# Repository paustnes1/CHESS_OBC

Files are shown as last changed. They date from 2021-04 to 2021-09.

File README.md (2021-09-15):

# CHESS OBC Revision 1.0

This PCB is the On-Board-Computer for the CHESS mission of the EPFL Spacecraft Team. It's core components are an FPGA which can be re-programmed via a PIC-Microcontroller. Furthermore the board hosts SRAM, FRAM, Flash, PC104 connector and some more smaller components.

The main project is in the Folder "CHESSOBC_rev1". The bill of materials (BOM) and the component placement list (CPL) is provided in Excel format. The zip contains the Gerber files which are used to produce the board.

The PCB is still in development and not in a final state.

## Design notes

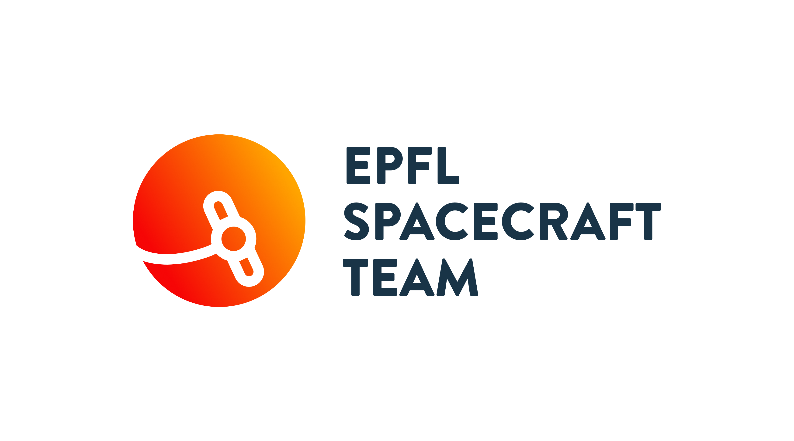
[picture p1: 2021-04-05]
CHESSOBC_rev1/SpacecraftTeam_light_BG.png

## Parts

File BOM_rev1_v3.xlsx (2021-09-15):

Designator | Manufacturer Nr. | Quantity | Type | Name | Description | Price / Unit | Mouser Link | Availability | LibRef
C1, C2, C4, C5, C7, C9, C10, C12, C13, C14, C15, C17, C19, C21, C23, C25, C27, C31, C33, C35, C37, C39, C41, C45, C47, C50, C52, C54, C56, C59, C63, C65, C69, C71, C74, C76, C80, C82, C87, C89 | GCM155L8EH104KE07D | 40 | Capacitor | 1005 | 100 nF | Fr.0.14 | GCM155L8EH104KE07D Murata Electronics | Mouser Schweiz (https://www.mouser.ch/ProductDetail/Murata-Electronics/GCM155L8EH104KE07D) | 302'380 in stock | CMP-2008-02046-1
C3 | JMK105BJ334KV-F | 1 | Capacitor | 1005 | 0.33 uF | Fr.0.11 | JMK105BJ334KV-F Taiyo Yuden | Mouser Schweiz (https://www.mouser.ch/ProductDetail/Taiyo-Yuden/JMK105BJ334KV-F) | 16'324 in stock | CMP-03422-001340-1
C6, C16, C18, C20, C22, C24, C26, C28, C29, C30, C32, C34, C36, C38, C40, C42, C43, C44, C46, C49, C51, C55, C57, C62, C64, C66, C68, C70, C73, C75, C78, C79, C81, C83, C86, C88 | 04025C103K4T2A | 36 | Capacitor | 1005 | 10 nF | Fr.0.09 | 04025C103K4T2A AVX | Mouser Schweiz (https://www.mouser.ch/ProductDetail/AVX/04025C103K4T2A) | 9382 in stock | CMP-1034-01878-1
C48, C53, C67, C77 | TMR107B7105KA-T | 4 | Capacitor | 1608 | 1 uF | Fr.0.24 | https://www.mouser.ch/ProductDetail/Taiyo-Yuden/TMR107B7105KA-T | 15'785 in stock | CMP-2000-06025-1
C58 | JMK212BBJ226MG8T | 1 | Capacitor | 0805 inches | 22 uF | Fr.0.27 | https://www.mouser.ch/ProductDetail/Taiyo-Yuden/JMK212BBJ226MG8T | 4960 in stock | CMP-001-00081-2
C100 | HMR325AC7475KM-P | 1 | Capacitor | 3225 | 4.7 uF | Fr.1.12 | https://www.mouser.ch/ProductDetail/Taiyo-Yuden/HMR325AC7475KM-P?qs=DPoM0jnrROVWw6RJv0JMZg%3D%3D | 1797 in stock | CMP-1038-02151-2
C8, C101 | LMK212AC6106KD-T | 2 | Capacitor | 0805 inches | 10 uF |  |  |  | CMP-2007-03243-2
COM-Header | 67996-420HLF | 1 | Header | 10X2 | COM-Header | Fr.0.69 | 67996-420HLF Amphenol FCI | Mouser Schweiz (https://www.mouser.ch/ProductDetail/Amphenol-FCI/67996-420HLF?qs=QKvFUfBIyQIvQWWcVN8Heg%3D%3D) | 6272 in stock
D1, D2 | ESD7351XV2T5G | 2 | Diode | T3V3S5 |  | Fr.0.41 | ESD7351XV2T5G ON Semiconductor | Mouser Schweiz (https://www.mouser.ch/ProductDetail/ON-Semiconductor/ESD7351XV2T5G?qs=byeeYqUIh0NOrh0ZBfew0g%3D%3D) | 7980 in stock | CMP-1063-00100-1
FLASH | IS37SML01G1-LLI | 1 | Flash | TC58CVG0S3HRAIJ | 1 Gbit | Fr.4.44 | IS37SML01G1-LLI ISSI | Mouser Schweiz (https://www.mouser.ch/ProductDetail/ISSI/IS37SML01G1-LLI?qs=YCa%2FAAYMW01%2FaQ6kjHyDew%3D%3D) | 928 in stock
FRAM | FM22LD16-55-BG | 1 | FRAM | FM22LD16-55-BG |  | Fr.39.50 | FM22LD16-55-BG Cypress Semiconductor | Mouser Schweiz (https://www.mouser.ch/ProductDetail/Cypress-Semiconductor/FM22LD16-55-BG?qs=pA5MXup5wxF9f7BYMzo1gA%3D%3D) | 1332 in stock
J1, J2 | ESQ-126-39-G-D | 2 | PC-104 | ESQ-126-23-T-D
PIC-Kit | 10129378-905003BLF | 1 | Header | 1X5 |  | Fr.0.17 | https://www.mouser.ch/ProductDetail/Amphenol-FCI/10129378-905003BLF?qs=0lQeLiL1qyYbn8n2WZpgeA%3D%3D | 3541 in stock
L2 | L0805C6R8MPWST | 1 | Inductor | 2012 | 6.8 uH | Fr.0.25 | https://www.mouser.ch/ProductDetail/KEMET/L0805C6R8MPWST?qs=gt1LBUVyoHlTFiSy3m2gEA%3D%3D | 2533 in stock
L3 | LQM21PN2R2NGCD | 1 | Inductor | 2012 | 2.2 uH | Fr.0.27 | LQM21PN2R2NGCD Murata Electronics | Mouser Schweiz (https://www.mouser.ch/ProductDetail/Murata-Electronics/LQM21PN2R2NGCD) | 95 in stock
5V-LED | BR1101W-TR | 2 | LED | RPG1102W-660-TR |  | Fr.0.38 | BR1101W-TR Stanley Electric | Mouser Schweiz (https://www.mouser.ch/ProductDetail/Stanley-Electric/BR1101W-TR?qs=byeeYqUIh0Pp62ktTXSSvA%3D%3D) | 16'982 in stock
LED_FPGA_1, LED_FPGA_2, LED_FPGA_3 | SMLD12BN1WT86 | 3 | LED | SMLD12BN1WT86 |  | Fr.0.66 | SMLD12BN1WT86 ROHM Semiconductor | Mouser Schweiz (https://www.mouser.ch/ProductDetail/ROHM-Semiconductor/SMLD12BN1WT86) | 6915 in stock
GPIO | 10129381-940002BLF | 1 | Header | Header 20X2 | GPIO-Header | Fr.0.77 | 10129381-940002BLF Amphenol FCI | Mouser Schweiz (https://www.mouser.ch/ProductDetail/Amphenol-FCI/10129381-940002BLF?qs=0lQeLiL1qybDkBpXY7DYcQ%3D%3D) | 357 in stock
PIC | PIC18LF26K83-I/SO | 1 | PIC | PIC18LF26K83-I/SO |  | Fr.2.00 | PIC18LF26K83-I/SO Microchip Technology | Mouser Schweiz (https://www.mouser.ch/ProductDetail/Microchip-Technology/PIC18LF26K83-I-SO/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) | 354 in stock
R1, R7, R9, R10, R11 | SG73P1EWTTP1002F | 5 | Resistor | RESC1005X40X25LL05T10 | 10 kOhm | Fr.0.27 | SG73P1EWTTP1002F KOA Speer | Mouser Schweiz (https://www.mouser.ch/ProductDetail/KOA-Speer/SG73P1EWTTP1002F) | 9600 in stock | CMP-2002-07353-1
R2 | ERA-2VEB2200X | 1 | Resistor | RESC1005X40X25ML05T10 | 220 Ohm | Fr.0.48 | ERA-2VEB2200X Panasonic | Mouser Schweiz (https://www.mouser.ch/ProductDetail/Panasonic/ERA-2VEB2200X?qs=sGAEpiMZZMtlubZbdhIBIFX24rZb7BVExcGQh2y83fs%3D) | 7790 in stock | CMP-2002-07511-1
R6 | MCS04020D1200BE000 | 1 | Resistor | RESC1005X40X25LL05T10 | 0 Ohm | Fr.0.43 | MCS04020D1200BE000 Vishay / Beyschlag | Mouser Schweiz (https://www.mouser.ch/ProductDetail/Vishay-Beyschlag/MCS04020D1200BE000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) | 19'725 in stock | CMP-2002-07353-1
R8 | MCS04020D4701BE000 | 1 | Resistor | RESC1005X40X25LL05T10 | 4.7 kOhm | Fr.0.51 | MCS04020D4701BE000 Vishay / Beyschlag | Mouser Schweiz (https://www.mouser.ch/ProductDetail/Vishay-Beyschlag/MCS04020D4701BE000) | 9990 in stock | CMP-2002-07353-1
R14, R15, R16, R17 | PA0603-R-070RL | 4 | Resistor | CRCW06030000Z0EA | 0 Ohm | Fr.0.53 | PA0603-R-070RL YAGEO | Mouser Schweiz (https://www.mouser.ch/ProductDetail/YAGEO/PA0603-R-070RL?qs=sGAEpiMZZMtlubZbdhIBIKX7RhrzB5EAvnsYZcgjSGA%3D) | 27'430 in stock
R18, R19, R20, R21, R22, R23 | CHP1206AFX-4701ELF | 6 | Resistor | CHP1206AFX-4701ELF | 4.7 kOhm | Fr.0.66 | CHP1206AFX-4701ELF Bourns | Mouser Schweiz (https://www.mouser.ch/ProductDetail/Bourns/CHP1206AFX-4701ELF) | 3331 in stock
R24, R25 | PTN0805Y1002BST1 | 2 | Resistor | PTN0805Y1002BST1 | 10 kOhm | Fr.1.40 | PTN0805Y1002BST1 Vishay / Thin Film | Mouser Schweiz (https://www.mouser.ch/ProductDetail/Vishay-Thin-Film/PTN0805Y1002BST1) | 1656 in stock
R100 | RC1206JR-07180RL | 1 | Resistor | RC1206JR-07180RL | 180 Ohm | Fr.0.19 | RC1206JR-07180RL YAGEO | Mouser Schweiz (https://www.mouser.ch/ProductDetail/YAGEO/RC1206JR-07180RL?qs=CteSnpDdeuBlMmDLUHPycw%3D%3D) | 172'831 in stock
R101 | RN73H2ATTD75R0B25 | 1 | Resistor | RN73H2ATTD75R0B25 | 75 Ohm | Fr.0.73 | RN73H2ATTD75R0B25 KOA Speer | Mouser Schweiz (https://www.mouser.ch/ProductDetail/KOA-Speer/RN73H2ATTD75R0B25) | 4'997 in stock
R_LED3_80Ohm, R_LED4_80Ohm, R_LED5_80Ohm | RCS060382R0FKEA | 3 | Resistor | RCS060382R0FKEA | 82 Ohm | Fr.0.15 | RCS060382R0FKEA Vishay / Dale | Mouser Schweiz (https://www.mouser.ch/ProductDetail/Vishay-Dale/RCS060382R0FKEA) | 5'286 in stock
SRAM | CY62167GE30-45BV1XI | 1 | SRAM | CY62167GE30-45BV1XI | 16 Mbit | Fr.18.13 | CY62167GE30-45BV1XI Cypress Semiconductor | Mouser Schweiz (https://www.mouser.ch/ProductDetail/Cypress-Semiconductor/CY62167GE30-45BV1XI?qs=3FnuM6ZipRIEqfAGSsiEJg%3D%3D) | 194 in stock
TempSensor | TMP144YFFT | 1 | Temperatur Sensor | TMP144YFFT |  | Fr.0.77 | TMP144YFFT Texas Instruments | Mouser Schweiz (https://www.mouser.ch/ProductDetail/Texas-Instruments/TMP144YFFT?qs=w%2Fv1CP2dgqo7c%252BU2xzWt2g%3D%3D) | 2130 in stock
U1 | A3P1000-1FGG484 | 1 | FPGA | A3P1000-1FGG484
CurrentSensing | INA138QPWRQ1 | 1 | Current Sense Amplifier | INA138QPWRQ1
1.5V-Supply | LM3671MF-3.3/NOPB | 1 | DC-DC Step down | LM3671MF-3.3/NOPB |  | Fr.1.52 | LM3671MF-3.3/NOPB Texas Instruments | Mouser Schweiz (https://www.mouser.ch/ProductDetail/Texas-Instruments/LM3671MF-33-NOPB?qs=QbsRYf82W3E7NHceZ4TukA%3D%3D) | 216 in stock
X1-(JTAG) | 77311-462K05LF | 1 | Header | 77311-462K05LF | PIC Header | Fr.0.82 | 77311-462K05LF Amphenol FCI | Mouser Schweiz (https://www.mouser.ch/ProductDetail/Amphenol-FCI/77311-462K05LF) | 337 in stock
FPGA-CLK | ECS-2033-320-AU | 1 | Oscilloscope | ECS-2033-320-AU |  | Fr.1.87 | ECS-2033-320-AU ECS | Mouser Schweiz (https://www.mouser.ch/ProductDetail/ECS/ECS-2033-320-AU) | 1595 in stock

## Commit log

2021-03-26 push first version
    [CHESSOBC_rev1.GBL, CHESSOBC_rev1.GBO, CHESSOBC_rev1.GBP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]
2021-03-27 Moved capacitors to FPGA
    First I deleted all the Components that were on our board. Then I copy pasted the layout from the Sapristi board. By "Design->Import changes..." all the connections should again be correct. The footprint was thereby changed to the same footprints we had before. Finally I changed to orientation of the capacitors to match with the ones of Sapristi.
    [CHESSOBC_rev1.GBL, CHESSOBC_rev1.GBO, CHESSOBC_rev1.GBP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]
2021-03-27 partially added debug interface
    [CHESSOBC_rev1.PrjPcb, GPIO_Headers.SchDoc]
2021-03-28 started on title block
    currently the new title block is on no schematic
    [CHESSOBC_rev1.PrjPcb, CHESSOBC_rev1.SCHLIB]
2021-03-29 added led circuits with correct components
    [CHESSOBC_rev1.PrjPcb, Core.SchDoc, GPIO_Headers.SchDoc]
2021-03-29 add3ed fram footprint
    [Core.SchDoc]
2021-03-29 added sram footprint
    [Core.SchDoc]
2021-03-29 Added 1V5 regulator for FPGA core
    [CHESSOBC_rev1.PcbDoc, Power.SchDoc]
2021-03-29 New FRAM and SRAM routed. Moved LEDs
    FRAM and SRAM has correct footprint
    LEDs and test points are moved to the power schematic to keep the structure. GPIO-headers should probably be moved to interface schematic. Footprints for leds must be updated
    [CHESSOBC_rev1.PcbDoc, Core.SchDoc, FPGABanks.SchDoc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]
2021-03-31 new leds with lower power consumption
    [CHESSOBC_rev1.PcbDoc, Interface.SchDoc, Power.SchDoc]
2021-04-02 Finished Title Block
    [CHESSOBC_rev1.PrjPcb, CHESSOBC_rev1.SCHLIB, Core.SchDoc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]
2021-04-03 Set up layer stack manager
    6 layers. Changed to mm. Added routing design rules
    [CHESSOBC_rev1.PcbDoc, CHESSOBC_rev1.PrjPcb, Core.SchDoc]
2021-04-03 started routing fram
    [CHESSOBC_rev1.PcbDoc, CHESSOBC_rev1.PrjPcb, FPGABanks.SchDoc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]
2021-04-05 TitleBlock, PC104 connections, FPGA/Ram placement
    TitleBlock: added Designer initials and fixed pictures
    PC104: Compared to endurosat and removed connections that don't exist on endurosat
    Placement: Placed FPGA, Sram and Fram in a place where it seems good
    [CHESSOBC_rev1.PcbDoc, CHESSOBC_rev1.PrjPcb, CHESSOBC_rev1.SCHLIB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]
2021-04-05 no big changes
    [CHESSOBC_rev1.PrjPcb, Core.SchDoc, FPGABanks.SchDoc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]
2021-04-05 Reconnected PC104 pins
    [Interface.SchDoc]
2021-04-05 pdf output job
    [CHESSOBC_rev1.PcbDoc]
2021-04-06 small changes
    [Memory.SchDoc]
2021-04-06 PC104 and cleanup of all comm pins
    [FPGABanks.SchDoc, GPIO_Headers.SchDoc, Interface.SchDoc]
2021-04-06 all connections (except 1.5V power) should be fine now
    [CHESSOBC_rev1.PcbDoc, FPGABanks.SchDoc, Housekeeping.SchDoc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]
2021-04-06 small error fix
    [CHESSOBC_rev1.PcbDoc]
2021-04-07 some changes for AP3000 comp.
    [FPGABanks.SchDoc, Interface.SchDoc]
2021-04-07 added current sensing
    [CHESSOBC_rev1.PcbDoc, Power.SchDoc]
2021-04-07 final cleaning before schem review
    [CHESSOBC_rev1.PcbDoc, FPGABanks.SchDoc, FPGABanks.~(6).SchDoc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]
2021-04-15 fpga fanout
    [CHESSOBC_rev1.PcbDoc]
2021-04-24 SRAM and FRAM fanout
    Fanout of SRAM and FRAM
    +Placement of a capacitor below FRAM
    [CHESSOBC_rev1.PcbDoc]
2021-04-27 Via placement for FPGA
    New design rule for tented vias
    Placed all vias under the FPGA
    (--> Still have to connect all of them with pads and add escape routes)
    [CHESSOBC_rev1.PcbDoc, CHESSOBC_rev1.PrjPcb]
2021-05-09 Started on fanout of FPGA
    Started with the outermost pins. Removed vias from the outermost row and put a track directly away from FPGA.
    [CHESSOBC_rev1.PcbDoc]
2021-05-09 Continued Fanout
    started conneting some power and ground pins in the center of FPGA. Added power and gnd plane (I hid the layer for more clarity while doing the fanout)
    [CHESSOBC_rev1.PcbDoc]
2021-05-15 Continued Fanout
    All pins that won't have to be moved are connected to a via. I made a list of pins which we should move to the edge of the FPGA.
    Every capacitor has via on it. 1V5 is always connected to a pin. 3v3 and GND are sometimes not connected to a pin (if there is no pin near it...)
    [CHESSOBC_rev1.PcbDoc]
2021-05-15 Started Fanout on 2nd Layer
    Placed some LED's on the board and started Fanout for FPGA on the 2nd layer.
    [CHESSOBC_rev1.PcbDoc]
2021-05-18 Continued fanout
    [CHESSOBC_rev1.PcbDoc]
2021-05-23 Fanout done
    [CHESSOBC_rev1.PcbDoc]
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2021-06-19 FRAM and SRAM with new design rules
    on FRAM and SRAM: changed track width to 0.15 and via size to 0.35pad/0.25hole
    [CHESSOBC_rev1.PcbDoc]
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2021-07-04 design rules
    all design rules should be respected now
    [CHESSOBC_rev1.PcbDoc]
2021-07-04 changed all to +3.3V net
    name was sometimes +3V3 instead of +3.3V
    [CHESSOBC_rev1.PcbDoc, CHESSOBC_rev1.PrjPcb, CHESSOBC_rev1.SCHLIB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]
2021-07-10 updated SPI-lines
    -updated spi-lines between Flash, FPGA, Pic
    (added pull up resistors)
    -moved all connections that were on NC of FPGA
    -placed all components on board
    [CHESSOBC_rev1.PcbDoc, CHESSOBC_rev1.SCHLIB, FPGABanks.SchDoc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]
2021-07-12 FPGA Fanout
    -Restarted fanout of FPGA
    -Added ground and power planes properly
    -Changed all vias to only have one small type of vias
    [CHESSOBC_rev1.PcbDoc, Memory.SchDoc]
2021-07-12 fanout
    only continued a bit
    [CHESSOBC_rev1.PcbDoc]
2021-07-13 all GND and 3.3V connected
    added vias or connections between all components and power/GND plane
    [CHESSOBC_rev1.PcbDoc]
2021-07-13 Fanout complete
    Fanout completed, escape routes not done yet
    [CHESSOBC_rev1.PcbDoc]
2021-07-15 SRAM routed
    Completely connected SRAM to FPGA
    [CHESSOBC_rev1.PcbDoc, CHESSOBC_rev1.PrjPcb, CHESSOBC_rev1.~(84).PcbDoc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]
2021-07-16 Flash routed
    all connections of Flash are connected
    [CHESSOBC_rev1.PcbDoc]
2021-07-16 PIC and PC104 routed
    [CHESSOBC_rev1.PcbDoc, FPGABanks.SchDoc]
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2021-07-19 COM Header routed and started GPIO header
    [CHESSOBC_rev1.PcbDoc, FPGABanks.SchDoc]
2021-07-19 everything routed
    GPIO pins routed
    [CHESSOBC_rev1.PcbDoc, FPGABanks.SchDoc]
2021-07-19 Changed many things suggested by ACI
    -Outline of board
    -Filled signal layers with GND
    -Spaced out lines a bit whenever possible
    -increased solder mask
    -moved vias away from pads, when possible
    -tented vias on both sides
    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
    [Memory.SchDoc]
2021-07-19 tested to create gerber files
    [CHESSOBC_rev1.GBL, CHESSOBC_rev1.GBO, CHESSOBC_rev1.GBP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]
2021-08-13 fixed solder mask
    added a hole into the solder mask, such that the components can be soldered on
    [CHESSOBC_rev1.PrjPcb]
2021-08-20 added BOM and CPL
    [BOM_rev1.xlsx, Pick Place for CHESSOBC_rev1.csv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]
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2021-09-15 changed current sense amplifier
    [BOM_rev1_v3.xlsx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]
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
